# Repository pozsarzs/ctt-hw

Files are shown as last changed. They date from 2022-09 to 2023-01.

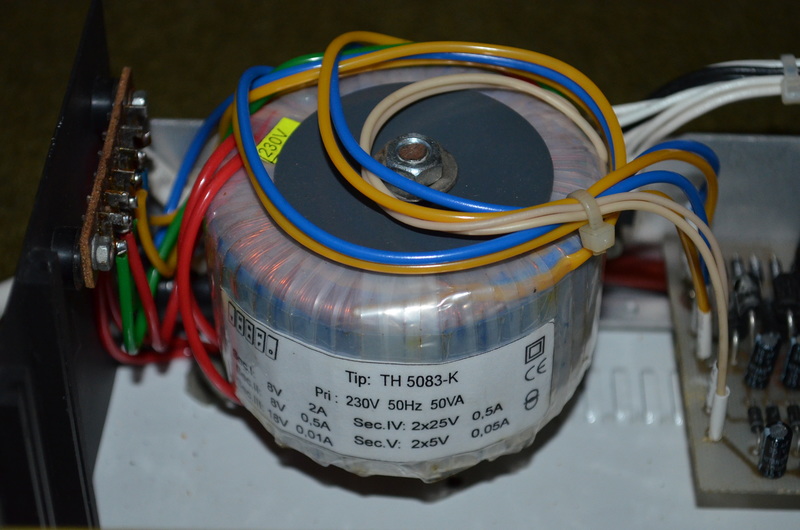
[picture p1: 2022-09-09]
photos/ctt-ps4.jpg

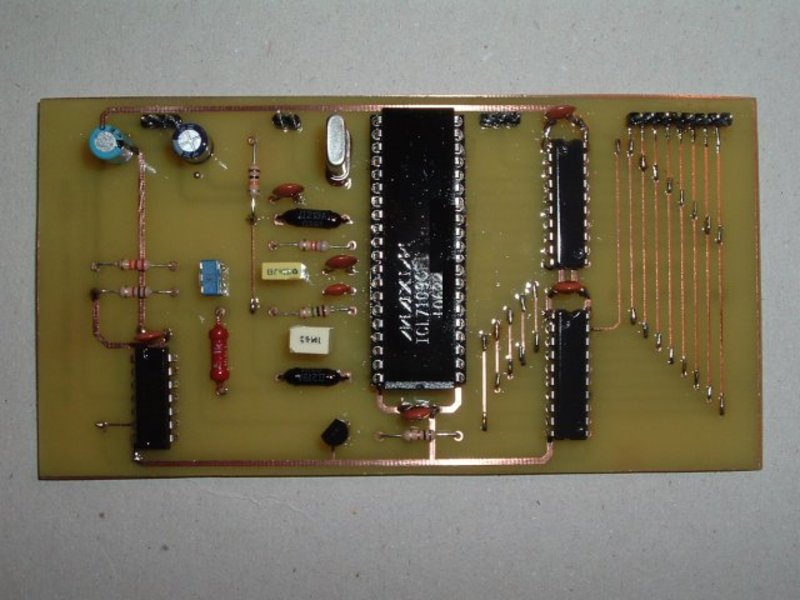
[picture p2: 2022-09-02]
photos/ctt-ad.jpg

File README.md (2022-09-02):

**CTT - transistor tester and characteristic curve plotter**  
Copyright (C) 2010-2022 Pozsár Zsolt <pozsarzs@gmail.com>  
Homepage: <http://www.pozsarzs.hu/>  
GitHub: <https://github.com/pozsarzs/ctt-hw>

**Documentation**

- version:             1.0
- language:            en
- licence:             CC-BY-NC-4.0

**Hardware**

 - version:            v120128

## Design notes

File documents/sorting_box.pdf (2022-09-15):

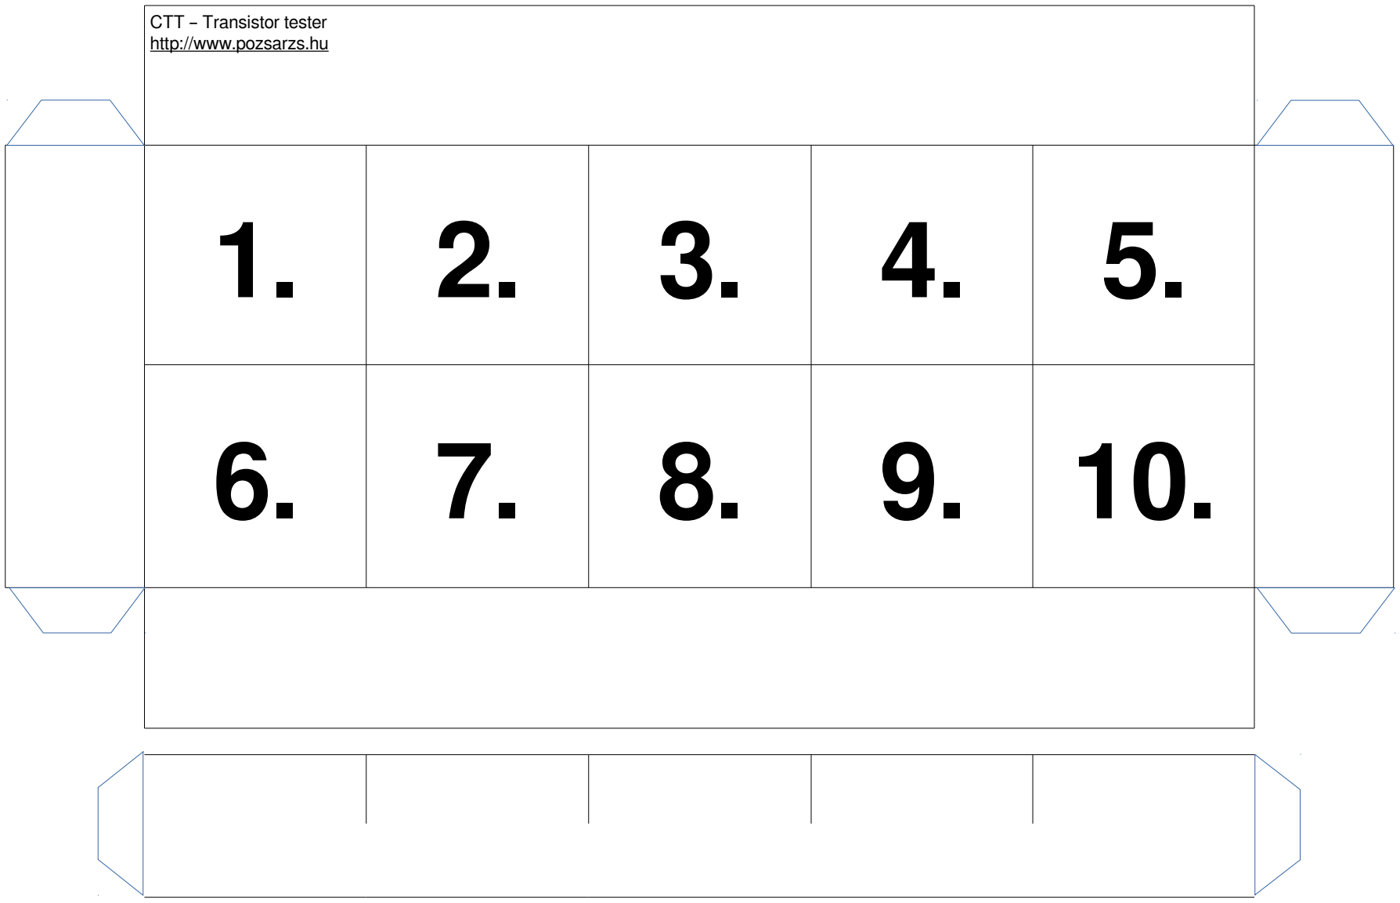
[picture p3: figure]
CTT – Transistor tester http://www.pozsarzs.hu

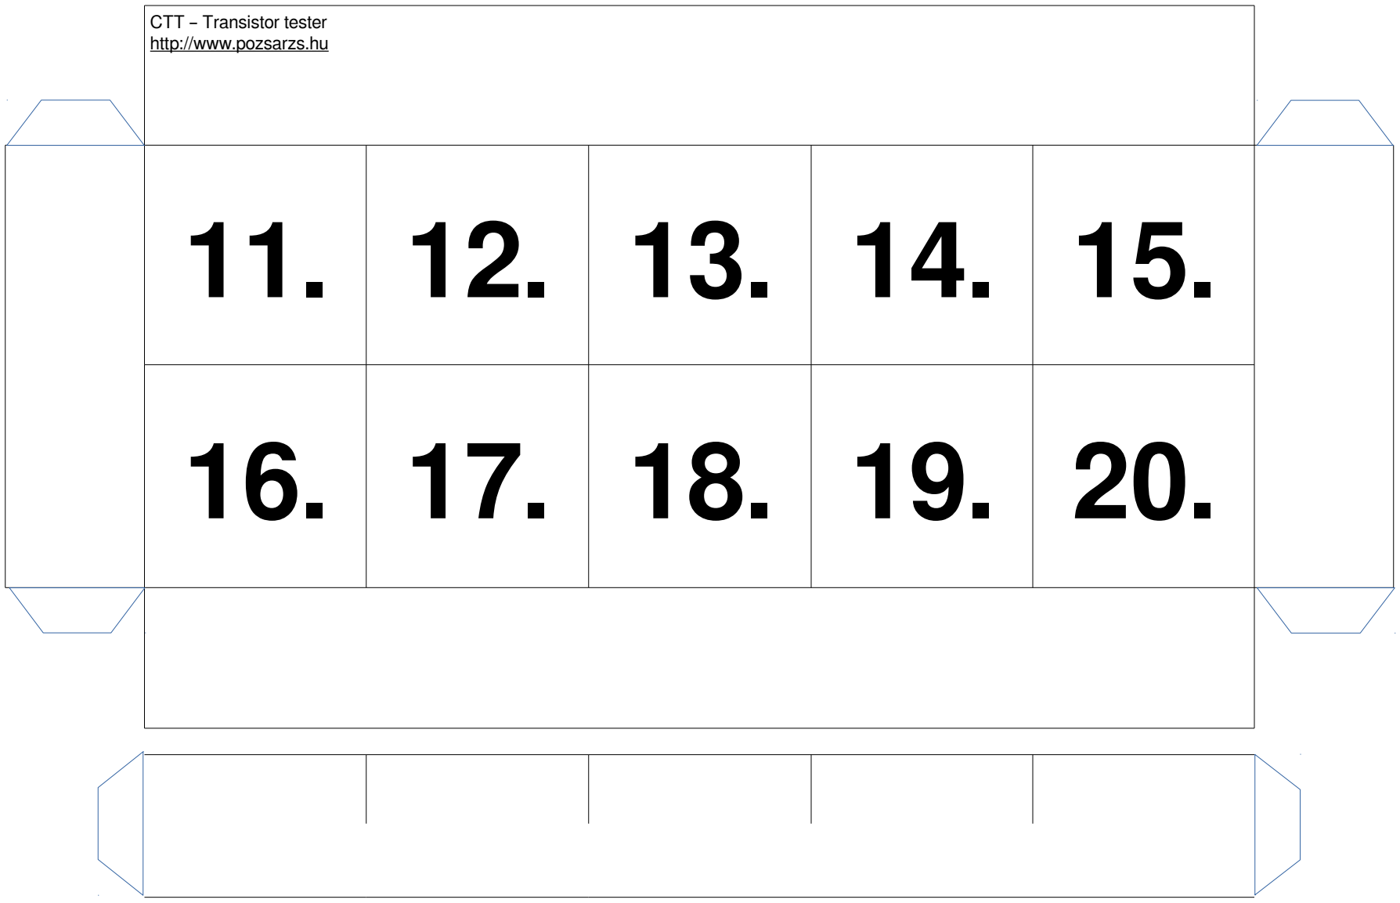
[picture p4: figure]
CTT – Transistor tester http://www.pozsarzs.hu

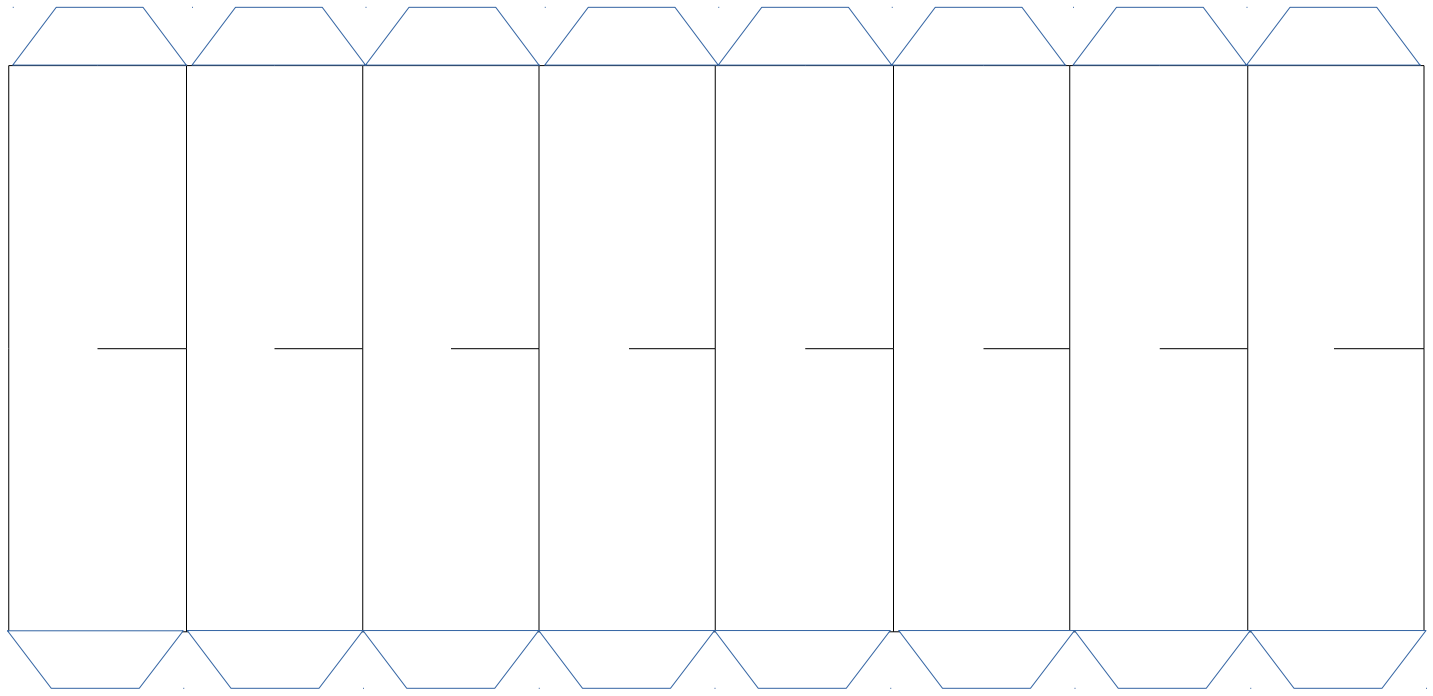
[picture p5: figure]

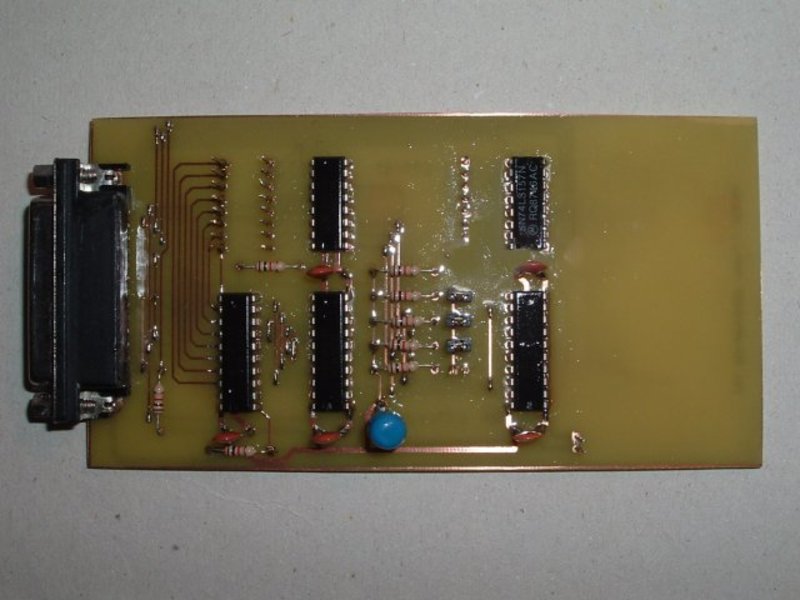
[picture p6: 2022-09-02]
photos/ctt-if.jpg

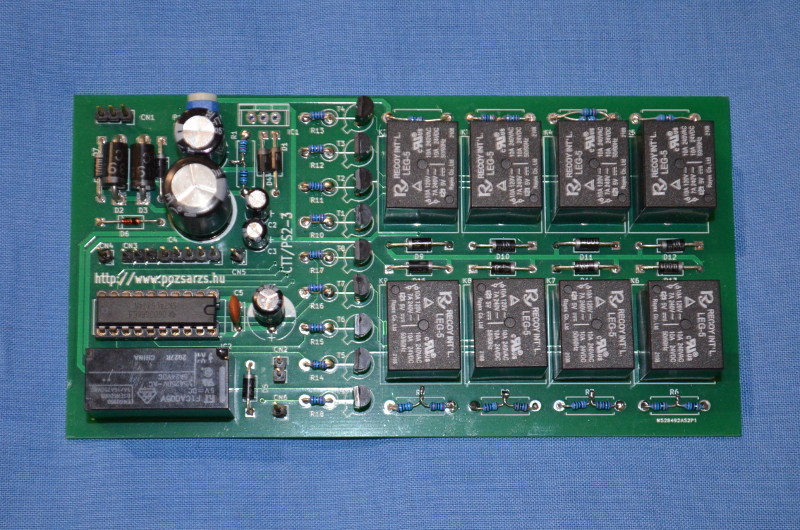
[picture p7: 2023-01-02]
photos/ctt-ps2.jpg

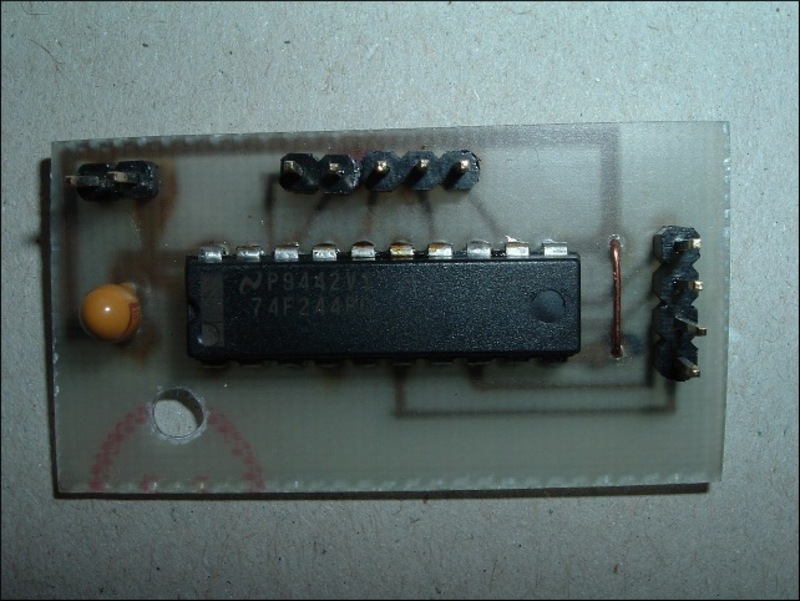
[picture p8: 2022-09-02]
photos/ctt-sc.jpg

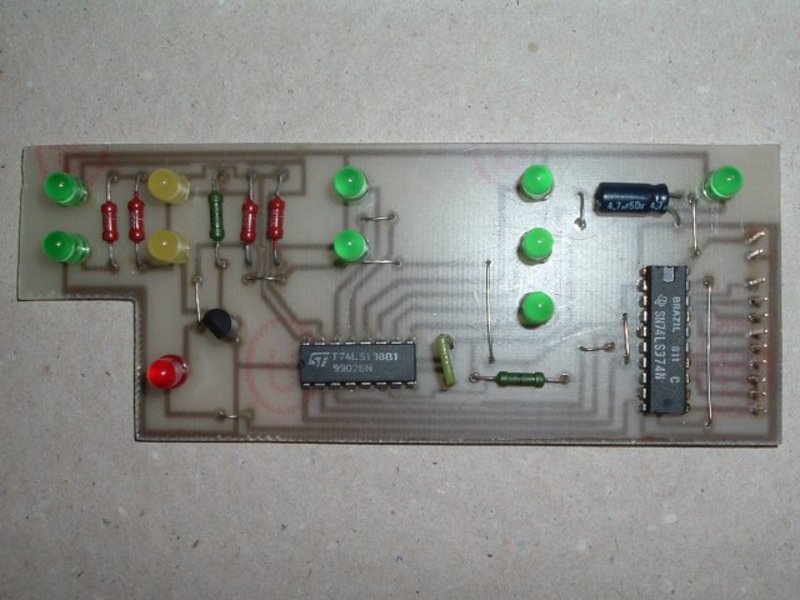
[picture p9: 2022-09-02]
photos/ctt-dp.jpg

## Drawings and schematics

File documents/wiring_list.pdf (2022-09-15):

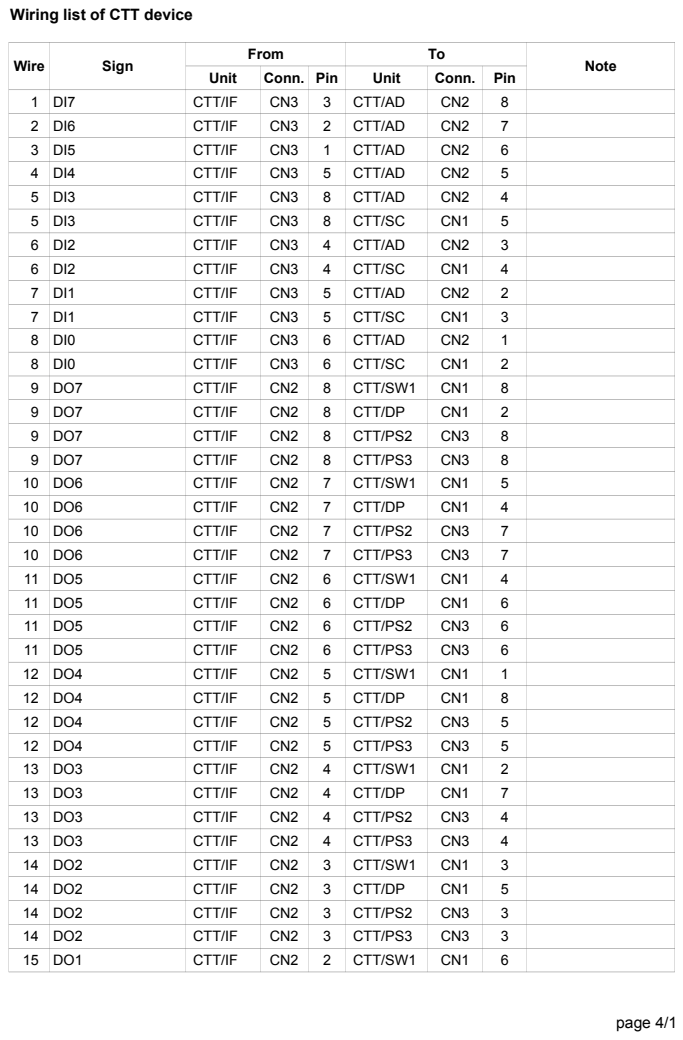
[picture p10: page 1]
Wire; Sign; From; Note; Unit; Conn. Pin; CTT/IF; CTT/AD; CTT/SC; CTT/SW1; CTT/DP; CTT/PS2; CTT/PS3

Wiring list of CTT device

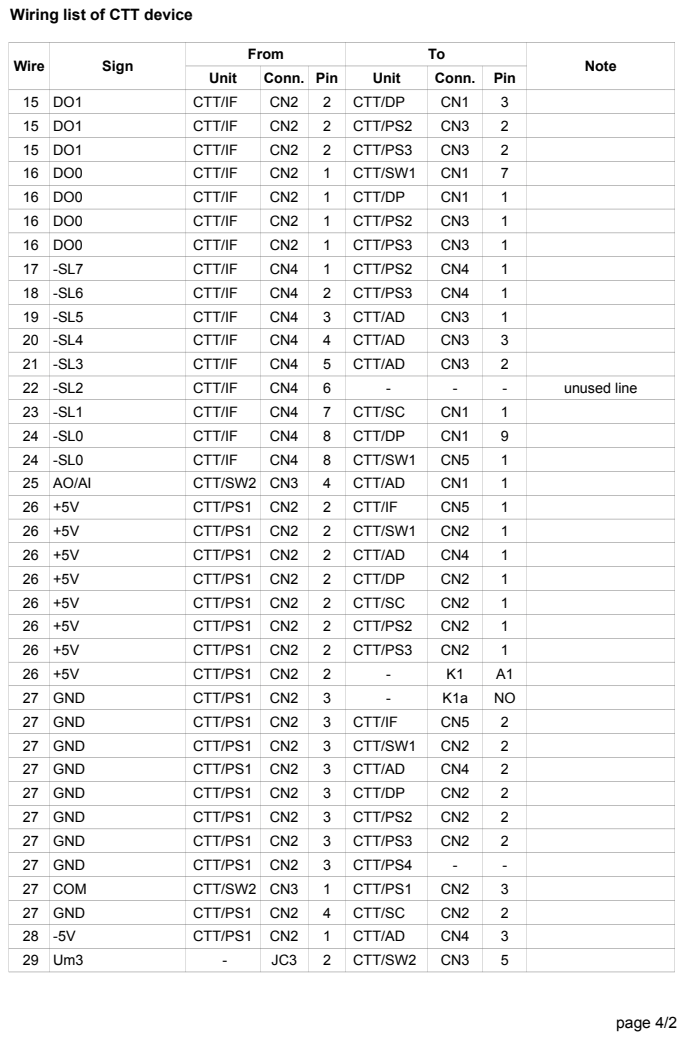
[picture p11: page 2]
Wire; Sign; Note; Unit; Conn. Pin; CTT/IF; CTT/DP; CTT/PS2; CTT/PS3; CTT/SW1; CTT/AD; unused line; CTT/SC; CTT/SW2 CN3; CTT/PS1 CN2; 27 GND; CTT/PS4; 27 COM; CTT/PS1; CTT/SW2

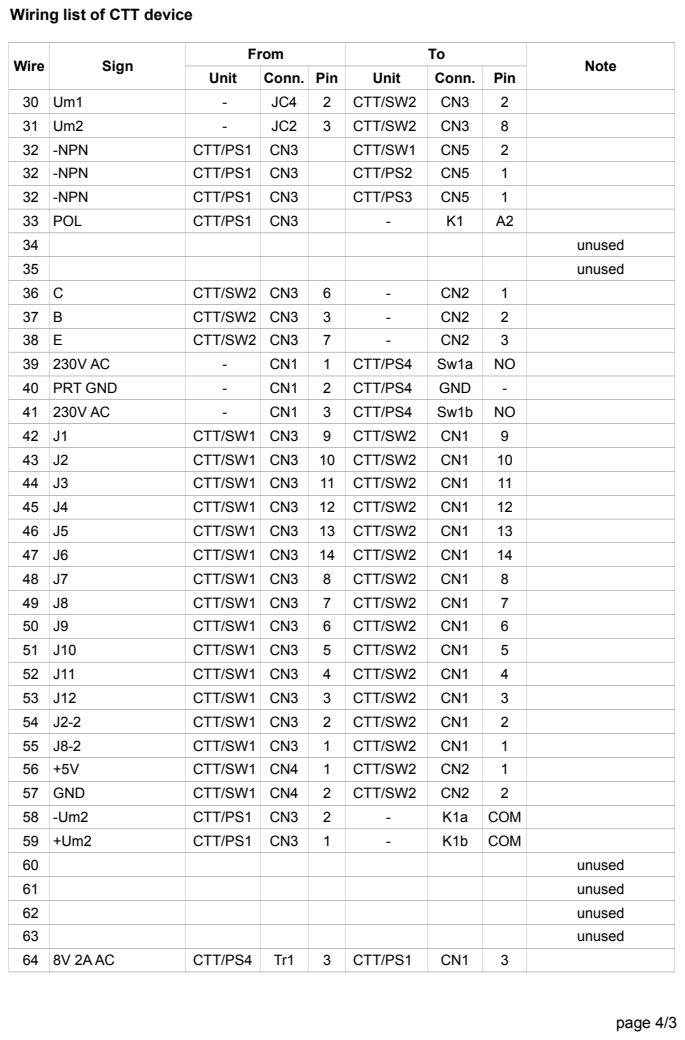
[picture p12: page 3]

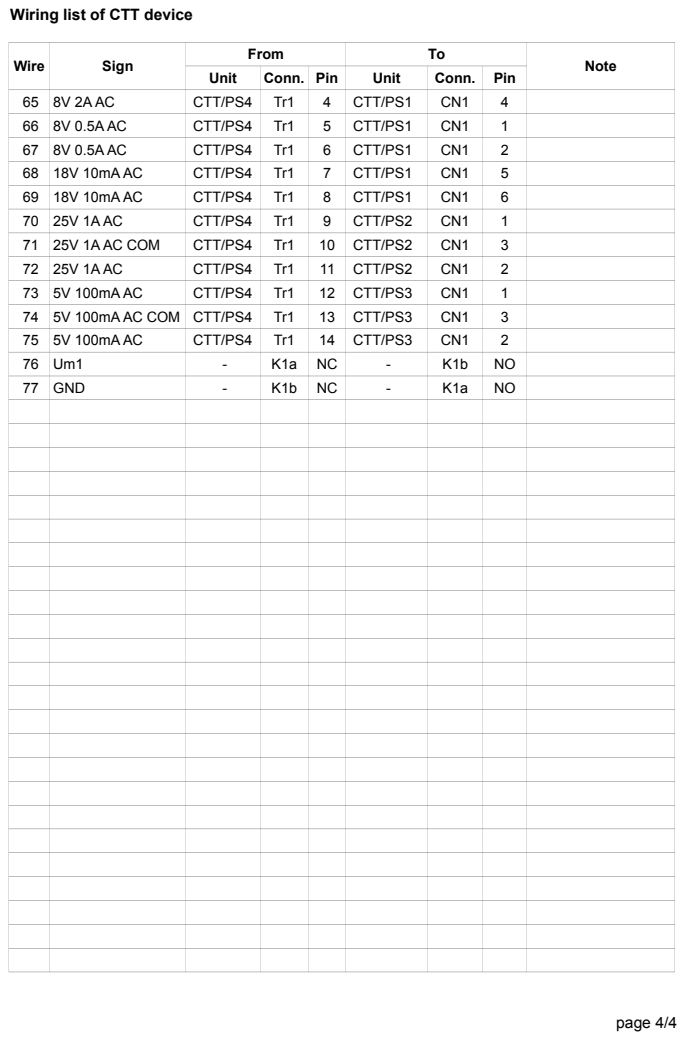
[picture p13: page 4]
Wire; Sign; Note; Unit; Conn. Pin; CTT/PS4; CTT/PS1; CTT/PS2; 71 25V 1A AC COM; 10 CTT/PS2; 11 CTT/PS2; 12 CTT/PS3; 74 5V 100mA AC COM CTT/PS4; 13 CTT/PS3; 14 CTT/PS3; 77 GND

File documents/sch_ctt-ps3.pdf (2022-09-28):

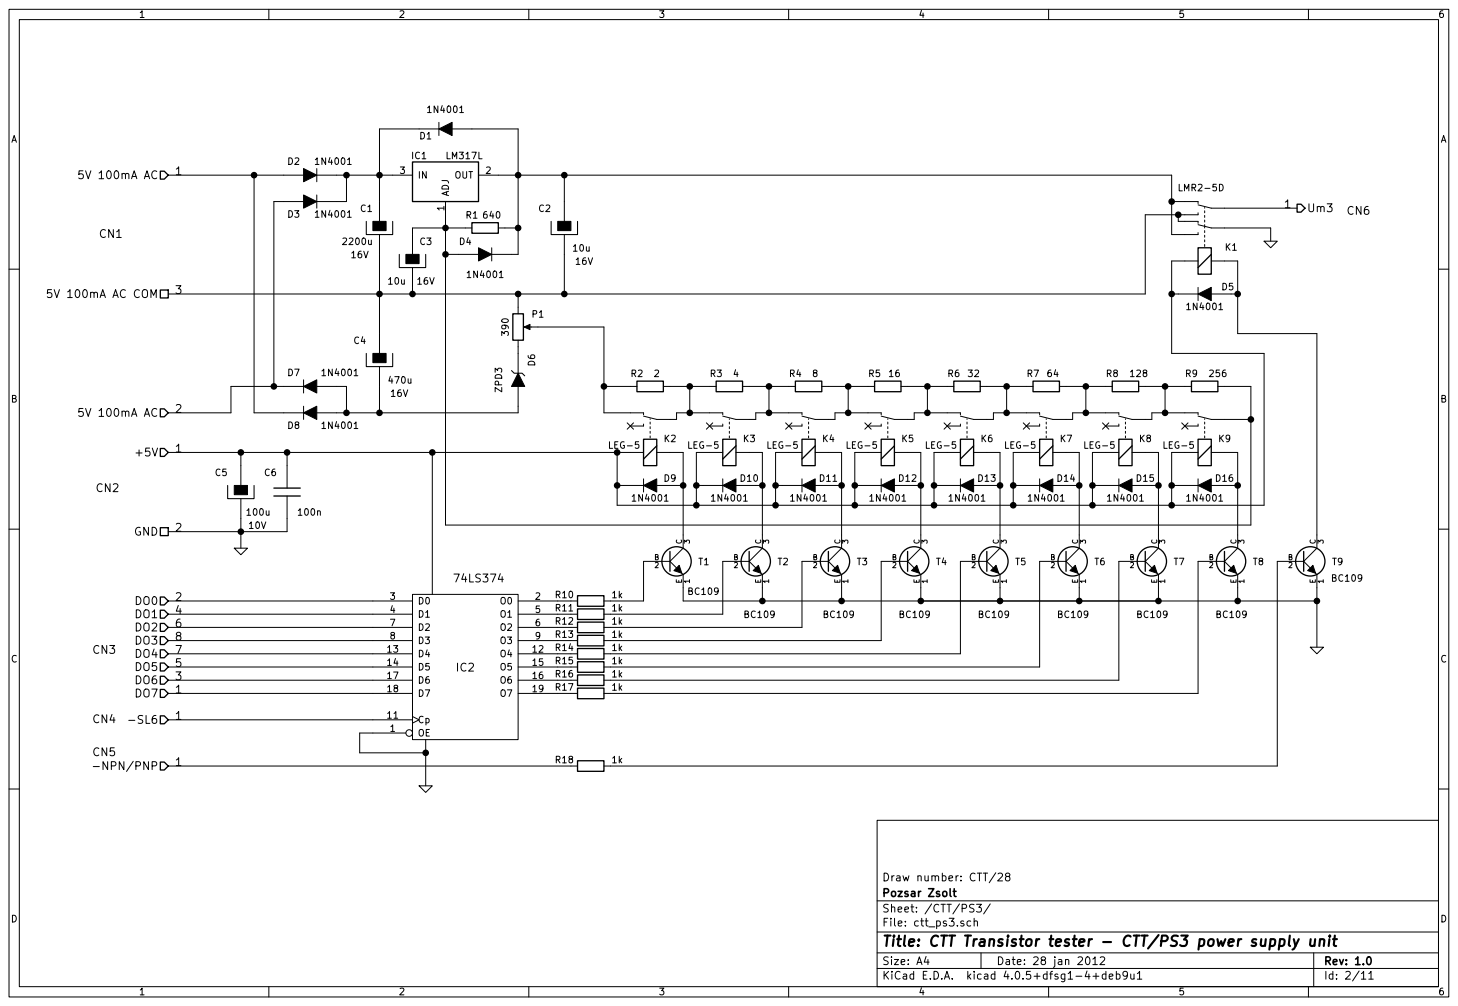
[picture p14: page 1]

File: ctt_ps3.sch Sheet: /CTT/PS3/ Pozsar Zsolt Draw number: CTT/28

Id: 2/11 Title: CTT Transistor tester - CTT/PS3 power supply unit

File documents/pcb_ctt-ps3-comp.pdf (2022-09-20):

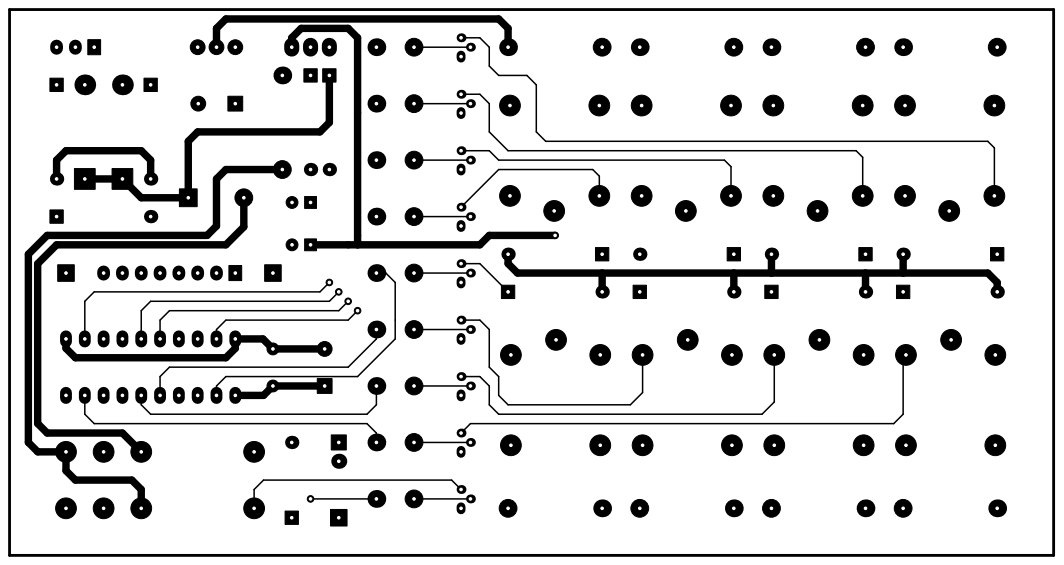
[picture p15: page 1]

File: ctt_ps3.kicad_pcb Sheet: Pozsar Zsolt Draw number: CTT/28, CTT/29-21

Id: 1/1 Title: CTT Transistor Tester - CTT/PS3 power supply unit

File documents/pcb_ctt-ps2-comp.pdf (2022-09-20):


File: ctt_ps2.kicad_pcb Sheet: Pozsar Zsolt Draw number: CTT/24, CTT/25-27

Id: 1/1 Title: CTT Transistor Tester - CTT/PS2 power supply unit

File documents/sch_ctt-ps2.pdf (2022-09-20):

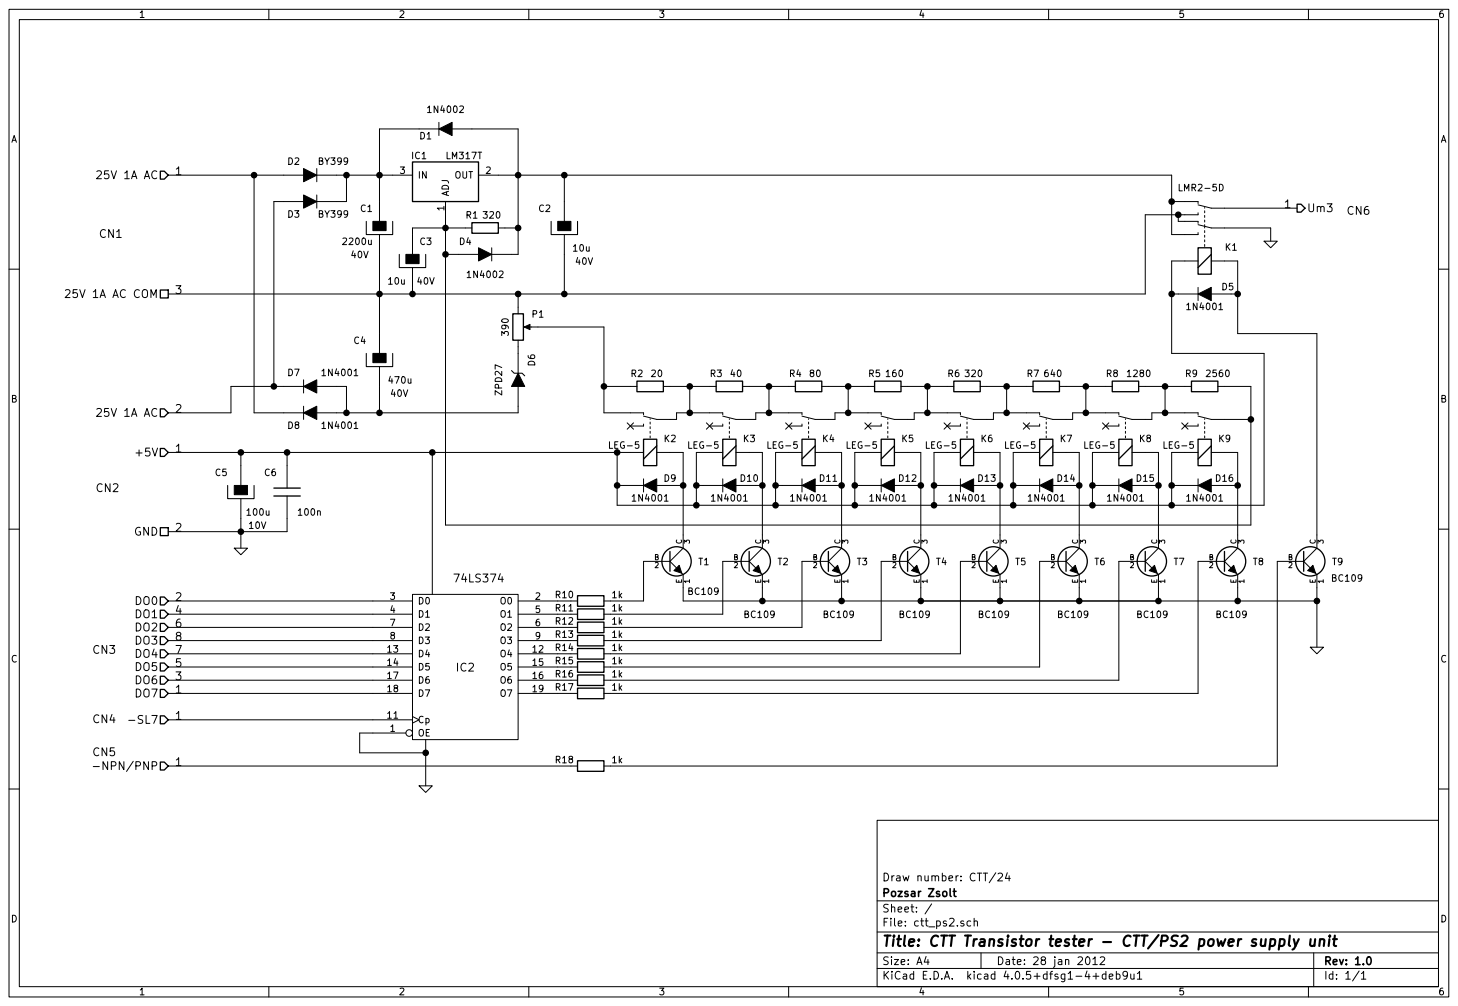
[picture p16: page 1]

File: ctt_ps2.sch Sheet: / Pozsar Zsolt Draw number: CTT/24

Id: 1/1 Title: CTT Transistor tester - CTT/PS2 power supply unit

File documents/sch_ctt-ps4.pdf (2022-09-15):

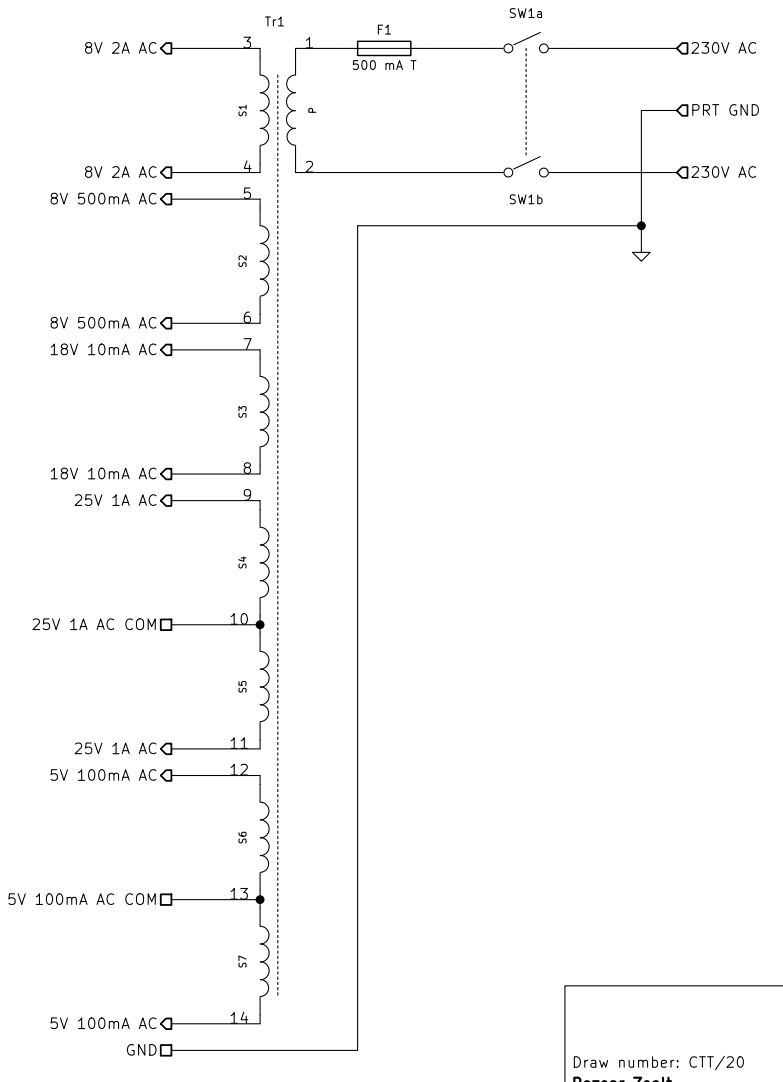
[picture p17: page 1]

File: ctt_ps4.sch Sheet: /CTT/PS4/ Pozsar Zsolt Draw number: CTT/20

Id: 10/11 Title: CTT Transistor tester - CTT/PS4 power supply unit

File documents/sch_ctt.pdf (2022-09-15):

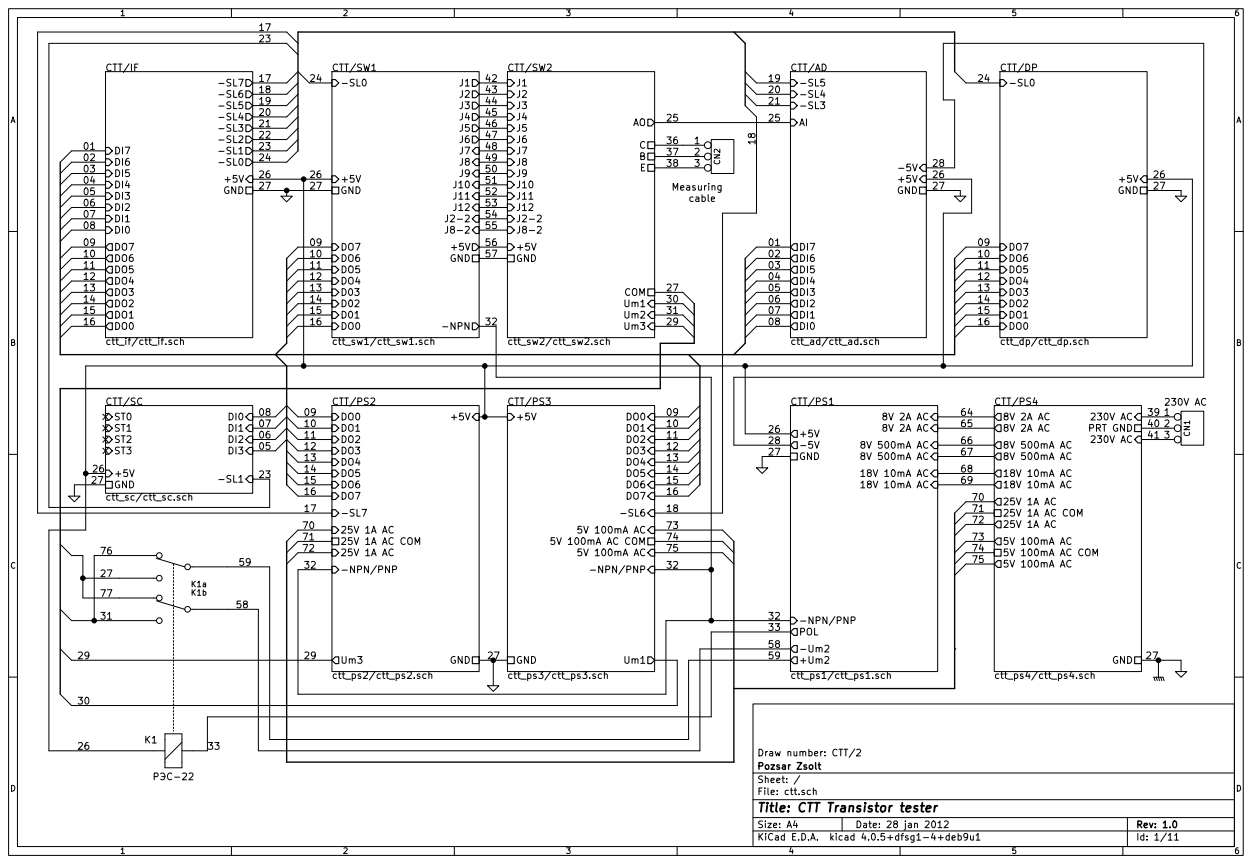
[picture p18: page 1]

33
58
59

Id: 1/11 Title: CTT Transistor tester File: ctt.sch Sheet: / Pozsar Zsolt Draw number: CTT/2 29
ctt_ps2/ctt_ps2.sch

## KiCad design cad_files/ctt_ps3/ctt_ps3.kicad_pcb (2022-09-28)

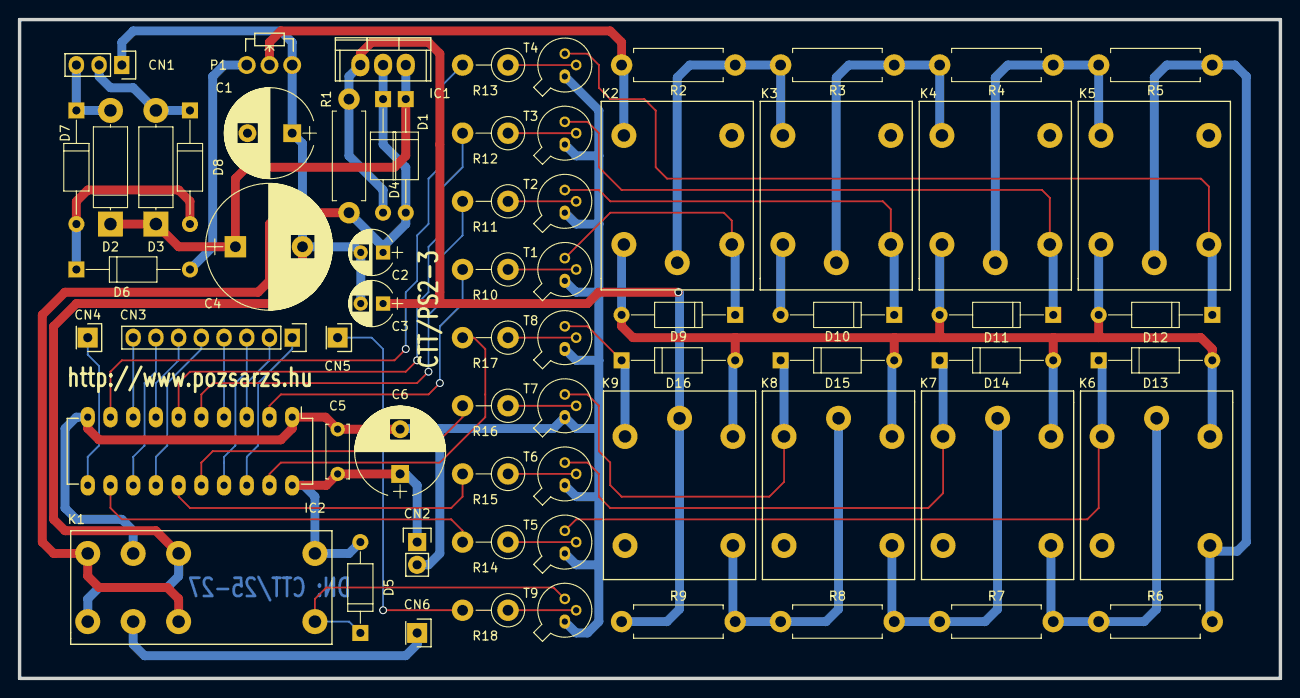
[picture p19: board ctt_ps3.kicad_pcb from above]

Board: 2 copper layers, 141.0 x 73.7 mm, 67 parts (0 on the bottom side), 43 nets.

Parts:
C1: 2200u; CP_Radial_D14.0mm_P7.50mm
C2, C3: 10u; CP_Radial_D5.0mm_P2.50mm
C4: 470u; CP_Radial_D10.0mm_P5.00mm
C5: 100u; CP_Radial_D10.0mm_P5.00mm
C6: 100n; C_Disc_D6.0mm_W2.5mm_P5.00mm
CN1: Pin_Header_Straight_1x03
CN2: Pin_Header_Straight_1x02
CN3: Pin_Header_Straight_1x08
CN4, CN5, CN6: Pin_Header_Straight_1x01
D1, D4: 1N4002; D_A-405_P12.70mm_Horizontal
D2, D3: BY399; D_5W_P12.70mm_Horizontal
D5: 1N4001; D_A-405_P10.16mm_Horizontal
D6: ZPD27; D_A-405_P12.70mm_Horizontal
D7, D8, D9, D10, D11, D12, D13, D14, D15, D16: 1N4001; D_A-405_P12.70mm_Horizontal
IC1: LM317L; TO-220
IC2: 74LS374; DIP-20_W7.62mm_LongPads
K1: LMR2-5D; relay_lmr2
K2, K3, K4, K5, K6, K7, K8, K9: LEG-5; relay_leg
P1: 390; Potentiometer_WirePads_Small
R1: 640; R_Axial_DIN0411_L9.9mm_D3.6mm_P12.70mm_Horizontal
R2: 2; R_Axial_DIN0411_L9.9mm_D3.6mm_P12.70mm_Horizontal
R3: 4; R_Axial_DIN0411_L9.9mm_D3.6mm_P12.70mm_Horizontal
R4: 8; R_Axial_DIN0411_L9.9mm_D3.6mm_P12.70mm_Horizontal
R5: 16; R_Axial_DIN0411_L9.9mm_D3.6mm_P12.70mm_Horizontal
R6: 32; R_Axial_DIN0411_L9.9mm_D3.6mm_P12.70mm_Horizontal
R7: 64; R_Axial_DIN0411_L9.9mm_D3.6mm_P12.70mm_Horizontal
R8: 128; R_Axial_DIN0411_L9.9mm_D3.6mm_P12.70mm_Horizontal
R9: 256; R_Axial_DIN0411_L9.9mm_D3.6mm_P12.70mm_Horizontal
R10, R11, R12, R13, R14, R15, R16, R17, R18: 1k; R_Axial_DIN0411_L9.9mm_D3.6mm_P5.08mm_Vertical
T1, T2, T3, T4, T5, T6, T7, T8, T9: BC109; TO-18-3

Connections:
/5V 100mA AC: D2.2, D3.2, D7.1, D8.1
/5V 100mA AC COM: C1.2, C2.2, C3.2, C4.1, K1.3, K1.6, P1.1
GND: C5.2, C6.2, IC2.1, IC2.10, K1.4, T1.1, T2.1, T3.1, T4.1, T5.1, T6.1, T7.1, T8.1, T9.1
unnamed: C1.1, D1.1, D2.1, D3.1, IC1.3
unnamed: C2.1, D1.2, D4.1, IC1.2, K1.5, K1.8, R1.1
unnamed: C3.1, D4.2, IC1.1, K9.3, R1.2, R9.1
unnamed: C4.2, D6.1, D7.2, D8.2
unnamed: D5.2, K1.2, T9.3
unnamed: D6.2, P1.3
unnamed: D9.2, K2.2, T1.3
unnamed: D10.2, K3.2, T2.3
unnamed: D11.2, K4.2, T3.3
unnamed: D12.2, K5.2, T4.3
unnamed: D13.2, K6.2, T5.3
unnamed: D14.2, K7.2, T6.3
unnamed: D15.2, K8.2, T7.3
unnamed: D16.2, K9.2, T8.3
unnamed: IC2.2, R10.2
unnamed: IC2.5, R11.2
unnamed: IC2.6, R12.2
unnamed: IC2.9, R13.2
unnamed: IC2.12, R14.2
unnamed: IC2.15, R15.2
unnamed: IC2.16, R16.2
unnamed: IC2.19, R17.2
unnamed: K2.3, K3.4, R2.1, R3.2
unnamed: K2.4, P1.2, R2.2
unnamed: K3.3, K4.4, R3.1, R4.2
unnamed: K4.3, K5.4, R4.1, R5.2
unnamed: K5.3, K6.4, R5.1, R6.2
unnamed: K6.3, K7.4, R6.1, R7.2
unnamed: K7.3, K8.4, R7.1, R8.2
unnamed: K8.3, K9.4, R8.1, R9.2
unnamed: R10.1, T1.2
unnamed: R11.1, T2.2
unnamed: R12.1, T3.2
unnamed: R13.1, T4.2
unnamed: R14.1, T5.2
unnamed: R15.1, T6.2
unnamed: R16.1, T7.2
unnamed: R17.1, T8.2
unnamed: R18.1, T9.2
VCC: C5.1, C6.1, D5.1, D9.1, D10.1, D11.1, D12.1, D13.1, D14.1, D15.1, D16.1, IC2.20, K1.1, K2.1, K3.1, K4.1, K5.1, K6.1, K7.1, K8.1, K9.1

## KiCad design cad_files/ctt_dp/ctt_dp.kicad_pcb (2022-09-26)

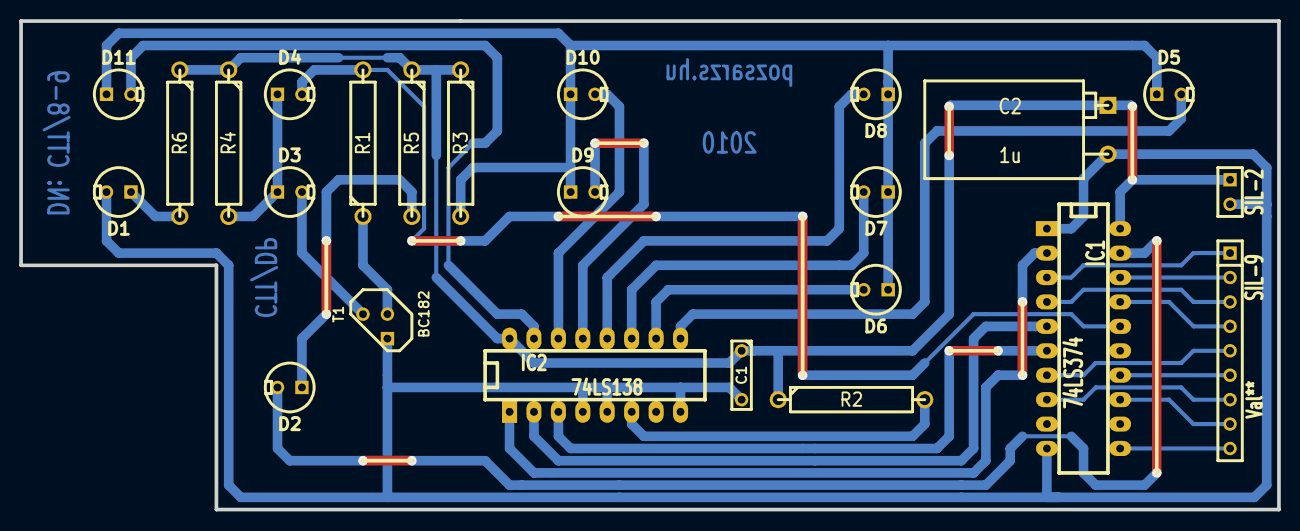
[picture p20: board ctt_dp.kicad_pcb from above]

Board: 2 copper layers, 130.8 x 50.8 mm, 24 parts (0 on the bottom side), 21 nets.

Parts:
C1: 33n; C2
C2: 1u; CPR10X16
D1, D2, D3, D4, D5, D6, D7, D8, D9, D10, D11: LED; LEDV
IC1: 74LS374; 20DIP-ELL300
IC2: 74LS138; 16DIP-ELL300
R1, R2: 1k; R6
R3, R4, R5, R6: 330; R6
SIL-2: Val**; SIL-2
SIL-9: Val**; SIL-9
T1: BC182; TO92

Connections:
+5V: C1.1, C2.1, IC1.20, IC2.16, R2.1, R3.1, R4.1, R5.1, R6.1
GND: C1.2, C2.2, D1.2, IC1.1, IC1.10, IC2.4, IC2.5, IC2.8, T1.1
unnamed: D1.1, R6.2
unnamed: IC2.6, R2.2
unnamed: R1.1, T1.2
unnamed: D4.2, IC1.16, R1.2
unnamed: D2.1, R5.2
unnamed: IC1.5, IC2.2
unnamed: D5.1, D6.1, D7.1, D8.1, D9.1, D10.1, D11.1, R3.2
unnamed: D6.2, IC2.10
unnamed: D8.2, IC2.12
unnamed: D10.2, IC2.14
unnamed: D11.2, IC2.15
unnamed: D9.2, IC2.13
unnamed: D7.2, IC2.11
unnamed: D5.2, IC2.9
unnamed: IC1.2, IC2.1
unnamed: IC1.6, IC2.3
unnamed: D3.1, D4.1, R4.2
unnamed: D3.2, T1.3
unnamed: D2.2, IC1.19

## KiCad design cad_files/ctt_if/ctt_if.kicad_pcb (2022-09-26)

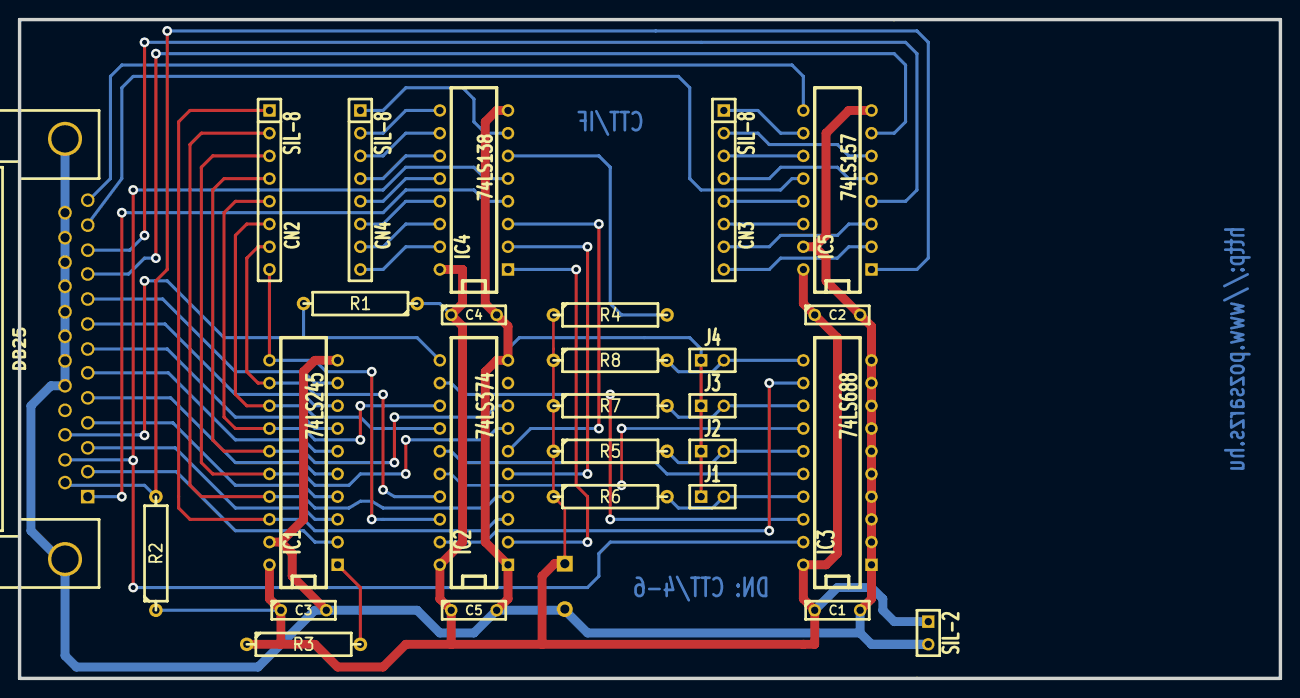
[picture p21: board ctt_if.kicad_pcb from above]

Board: 2 copper layers, 141.0 x 73.7 mm, 28 parts (1 on the bottom side), 39 nets.

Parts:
C1, C2, C3, C4, C5: 33n; C2
C6: 100u; CPR10X16
CN1: DB25; DB25FC
IC1: 74LS245; 20dip300
IC2: 74LS374; 20dip300
IC3: 74LS688; 20dip300
IC4: 74LS138; 16dip300
IC5: 74LS157; 16dip300
J1, J2, J3, J4: JUMPER; SIL-2
R1, R2, R3, R4, R5, R6, R7, R8: 1k; R5
SIL-2: CN5; SIL-2
SIL-8: CN3; SIL-8
SIL-8#2: CN4; SIL-8
SIL-8#3: CN2; SIL-8

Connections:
/+5V: C1.1, C2.1, C3.1, C4.1, C5.1, C6.1, IC1.20, IC2.20, IC3.20, IC4.16, IC5.16, R1.1, R2.1, R3.1, R4.1, R5.1, R6.1, R7.1, R8.1
/DO0: IC1.18, IC2.3
/DO1: IC1.17, IC2.4
/DO2: IC1.16, IC2.7
/DO3: IC1.15, IC2.8
/DO4: IC1.14, IC2.13
/DO5: IC1.13, IC2.14
/DO6: IC1.12, IC2.17
/DO7: IC1.11, IC2.18
/GND: C1.2, C2.2, C3.2, C4.2, C5.2, C6.2, CN1.18, CN1.19, CN1.20, CN1.21, CN1.22, CN1.23, CN1.24, CN1.25, IC1.10, IC1.19, IC2.1, IC2.10, IC3.1, IC3.2, IC3.3, IC3.4, IC3.5, IC3.6, IC3.7, IC3.8, IC3.9, IC3.10, IC4.8, IC5.8, IC5.15, J1.1, J2.1, J3.1, J4.1
unnamed: IC3.11, J4.2, R8.2
unnamed: IC3.13, J3.2, R7.2
unnamed: IC3.15, J2.2, R5.2
unnamed: IC2.15, IC3.16
unnamed: IC2.19, IC3.12
unnamed: IC3.17, J1.2, R6.2
unnamed: CN1.1, IC4.4
unnamed: IC2.5, IC4.2
unnamed: CN1.2, IC1.2
unnamed: IC2.16, IC3.14
unnamed: IC2.12, IC3.18
unnamed: CN1.16, IC2.11, R1.2
unnamed: CN1.13, IC5.9
unnamed: CN1.14, IC5.1, R2.2
unnamed: CN1.15, IC3.19, IC4.5
unnamed: CN1.12, IC5.12
unnamed: IC1.1, R3.2
unnamed: CN1.11, IC5.4
unnamed: IC4.6, R4.2
unnamed: CN1.4, IC1.4
unnamed: CN1.6, IC1.6
unnamed: CN1.8, IC1.8
unnamed: IC2.6, IC4.3
unnamed: IC2.2, IC4.1
unnamed: CN1.10, IC5.7
unnamed: CN1.9, IC1.9
unnamed: CN1.7, IC1.7
unnamed: CN1.5, IC1.5
unnamed: CN1.3, IC1.3

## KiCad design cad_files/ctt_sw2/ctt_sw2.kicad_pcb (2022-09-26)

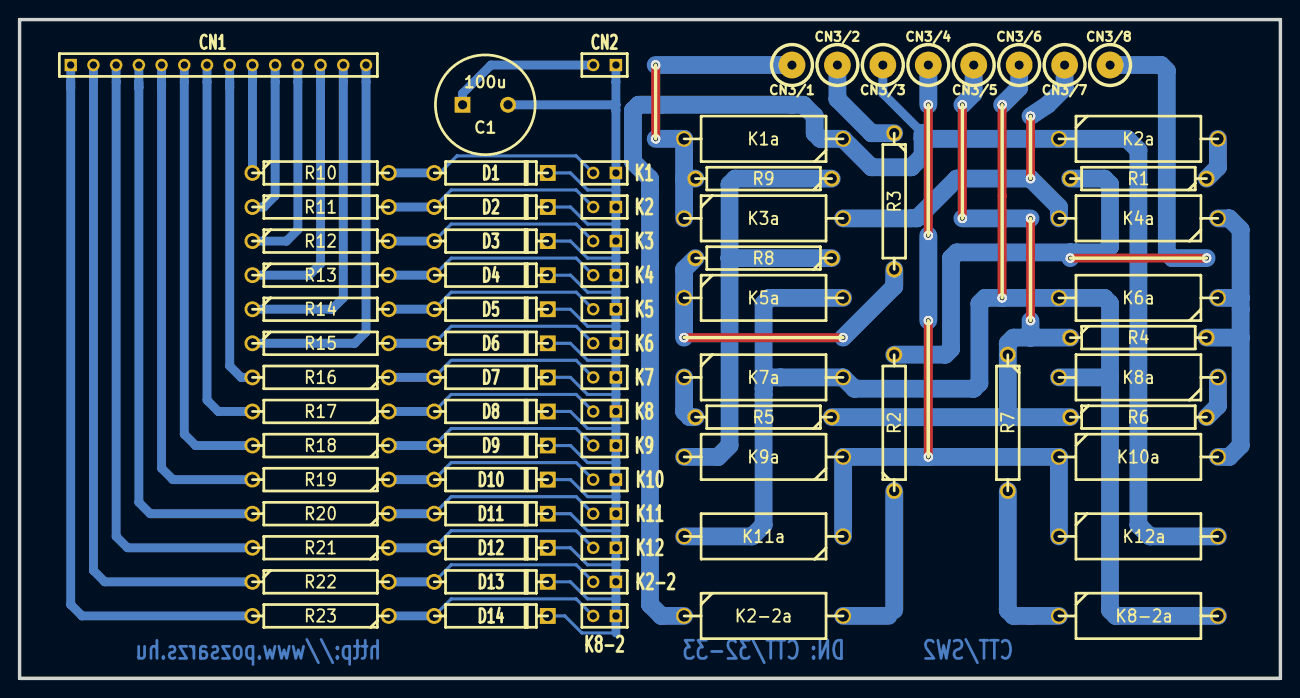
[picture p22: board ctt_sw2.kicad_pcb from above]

Board: 2 copper layers, 141.0 x 73.7 mm, 76 parts (0 on the bottom side), 30 nets.

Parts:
1PIN: CN3/8; 1pin3
1PIN#2: CN3/7; 1pin3
1PIN#3: CN3/6; 1pin3
1PIN#4: CN3/1; 1pin3
1PIN#5: CN3/2; 1pin3
1PIN#6: CN3/3; 1pin3
1PIN#7: CN3/4; 1pin3
1PIN#8: CN3/5; 1pin3
C1: 100u; C2V10
D1, D2, D3, D4, D5, D6, D7, D8, D9, D10, D11, D12, D13, D14: 1N4148; D5
K1, K2, K2-2, K3, K4, K5, K6, K7, K8, K8-2, K9, K10, K11, K12: Reed_relay; SIL-2
K1a, K2-2a, K2a, K3a, K4a, K5a, K6a, K7a, K8-2a, K8a, K9a, K10a, K11a, K12a: SPST; R7
R1, R5: 100_1%; R6
R2, R10, R11, R12, R13, R14, R15, R16, R17, R18, R19, R20, R21, R22, R23: R; R6
R3: 33K; R6
R4: 1k_1%; R6
R6: 1_1%_1W; R6
R7: ?_1%_1W; R6
R8: 900K_1%; R6
R9: 100k_1%; R6
SIL-2: CN2; SIL-2
SIL-14: CN1; SIL-14

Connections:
0-1V_1: R1.2, R2.2
0-20V_1: R4.1, R5.1, R6.1, R7.1
+5V_1: C1.1, D1.2, D2.2, D3.2, D4.2, D5.2, D6.2, D7.2, D8.2, D9.2, D10.2, D11.2, D12.2, D13.2, D14.2, K1.1, K2.1, K2-2.1, K3.1, K4.1, K5.1, K6.1, K7.1, K8.1, K8-2.1, K9.1, K10.1, K11.1, K12.1
Base_1: K1a.1, K2-2a.1, K2a.1, K12a.2
COM_1: K1a.2, K3a.1, R9.2
Collector_1: K5a.2, K6a.2, K7a.2, K8-2a.2, K8a.2, K11a.2
Emitter_1: K3a.2, K4a.2
unnamed: D12.1, K12.2, R21.1
unnamed: D11.1, K11.2, R20.1
unnamed: D10.1, K10.2, R19.1
unnamed: D9.1, K9.2, R18.1
unnamed: D7.1, K7.2, R16.1
unnamed: D3.1, K3.2, R12.2
unnamed: D4.1, K4.2, R13.2
unnamed: D5.1, K5.2, R14.2
unnamed: D2.1, K2.2, R11.2
unnamed: K2-2a.2, R2.1
unnamed: K4a.1, K6a.1, K10a.2, R4.2
unnamed: K7a.1, R5.2
unnamed: K8-2a.1, R7.2
unnamed: K8a.1, R6.2
unnamed: K5a.1, R3.2, R8.2
unnamed: K2a.2, R1.1
unnamed: K9a.2, R8.1, R9.1
unnamed: D1.1, K1.2, R10.2
unnamed: D13.1, K2-2.2, R22.2
unnamed: D6.1, K6.2, R15.2
unnamed: D14.1, K8-2.2, R23.1
unnamed: D8.1, K8.2, R17.1
Um_1: K9a.1, K10a.1, K11a.1, K12a.1

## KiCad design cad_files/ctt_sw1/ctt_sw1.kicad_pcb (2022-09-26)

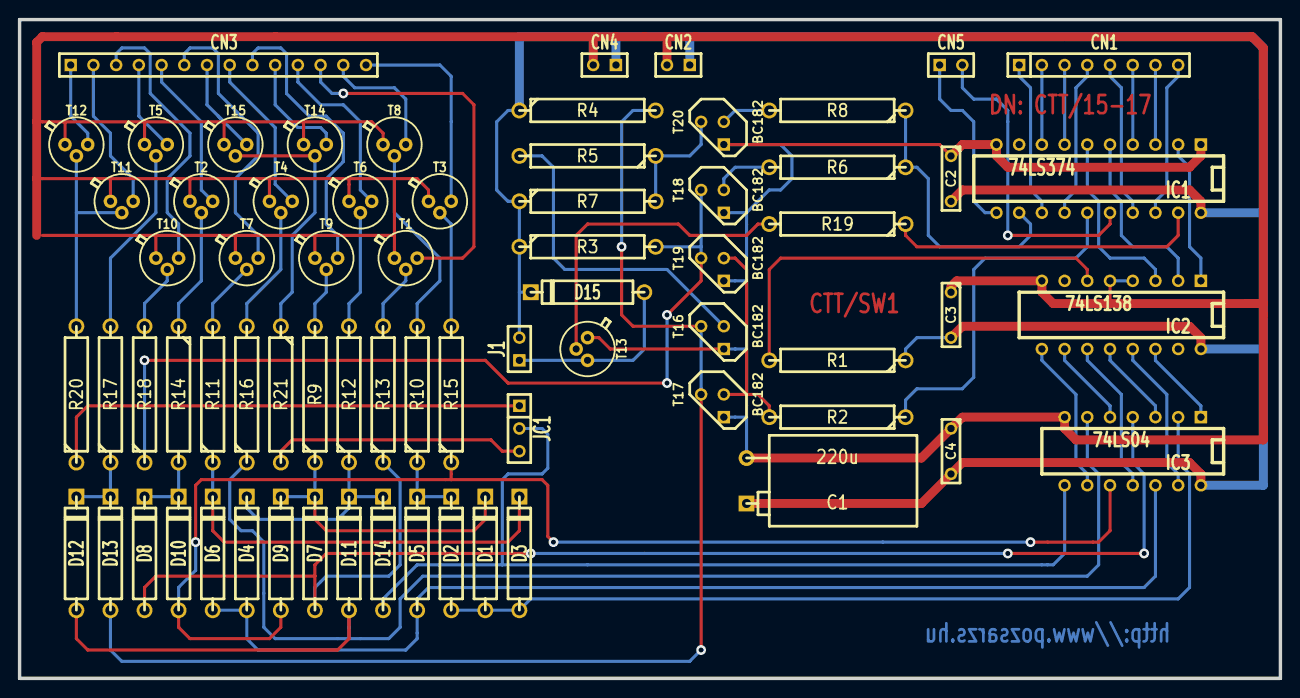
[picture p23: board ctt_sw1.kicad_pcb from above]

Board: 2 copper layers, 141.0 x 73.7 mm, 70 parts (0 on the bottom side), 50 nets.

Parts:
C1: 220u; CPR10X16
C2, C3, C4: 100n; C2
D1, D2, D3, D4, D5, D6, D7, D8, D9, D10, D11, D12, D13, D14, D15: 1N4148; D5
IC1: 74LS374; DIP-20__300
IC2: 74LS138; DIP-16__300
IC3: 74LS04; DIP-14__300
J1: Reed_relay; SIL-2
JC1: SWITCH_INV; SIL-3
R1, R2, R3, R4, R5, R6, R7, R8, R9, R10, R11, R12, R13, R14, R15, R16, R17, R18, R19, R20, R21: 1k; R6
SIL-2: CN4; SIL-2
SIL-2#2: CN5; SIL-2
SIL-2#3: CN2; SIL-2
SIL-8: CN1; SIL-8
SIL-14: CN3; SIL-14
T1, T2, T3, T4, T5, T6, T7, T8, T9, T10, T11, T12, T13, T14, T15: BC109C; TO18EBC
T16, T17, T18, T19, T20: BC182; TO92

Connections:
/+5V: C1.1, C2.2, C3.2, C4.2, D15.2, IC1.20, IC2.16, IC3.14, J1.2, R1.1, R3.1, R4.1, R7.1
GND: C1.2, C2.1, C3.1, C4.1, IC1.1, IC1.10, IC2.4, IC2.5, IC2.8, IC3.7, T1.1, T2.1, T3.1, T4.1, T5.1, T6.1, T7.1, T8.1, T9.1, T10.1, T11.1, T12.1, T13.1, T14.1, T15.1, T16.1, T17.1, T18.1, T19.1, T20.1
unnamed: D13.1, R4.2, T16.3, T17.3
unnamed: R3.2, R18.1, T18.3, T19.3
unnamed: R2.2, T17.2, T19.2
unnamed: D1.2, D7.2, D9.2, R9.1
unnamed: D4.2, D11.2, D14.2, R12.1
unnamed: R20.2, T11.2, T12.2
unnamed: D1.1, D2.1, D3.1, IC3.2
unnamed: D4.1, D5.1, D6.1, IC3.12
unnamed: D3.2, D6.2, R11.1
unnamed: IC1.19, R19.1
unnamed: R19.2, T13.2
unnamed: JC1.3, R21.2
unnamed: JC1.1, R20.1
unnamed: R15.2, T3.2
unnamed: R14.1, T2.2
unnamed: IC1.15, R2.1
unnamed: R8.2, T20.2
unnamed: IC1.12, R6.1, R8.1
unnamed: R6.2, T18.2
unnamed: R5.2, T16.2
unnamed: R13.2, T1.2
unnamed: R12.2, T6.2
unnamed: R10.2, T8.2
unnamed: R9.2, T9.2
unnamed: IC2.9, IC3.9
unnamed: IC2.11, IC3.11
unnamed: IC2.12, IC3.3
unnamed: IC2.13, IC3.13
unnamed: IC2.6, R1.2
unnamed: IC2.10, IC3.5
unnamed: D14.1, IC3.8, JC1.2
unnamed: IC2.14, IC3.1
unnamed: R17.2, T5.2
unnamed: R21.1, T14.2, T15.2
unnamed: R11.2, T7.2
unnamed: R16.2, T4.2
unnamed: IC1.2, IC2.1
unnamed: IC1.5, IC2.2
unnamed: IC1.6, IC2.3
unnamed: R18.2, T10.2
unnamed: D15.1, J1.1, T13.3
unnamed: R5.1, R7.2, T20.3
unnamed: D2.2, D5.2, R10.1
unnamed: D8.2, D10.2, R14.2
unnamed: D12.2, D13.2, R17.1
unnamed: D7.1, D8.1, IC3.4, R13.1
unnamed: D9.1, D10.1, IC3.10, R15.1
unnamed: D11.1, D12.1, IC3.6, R16.1

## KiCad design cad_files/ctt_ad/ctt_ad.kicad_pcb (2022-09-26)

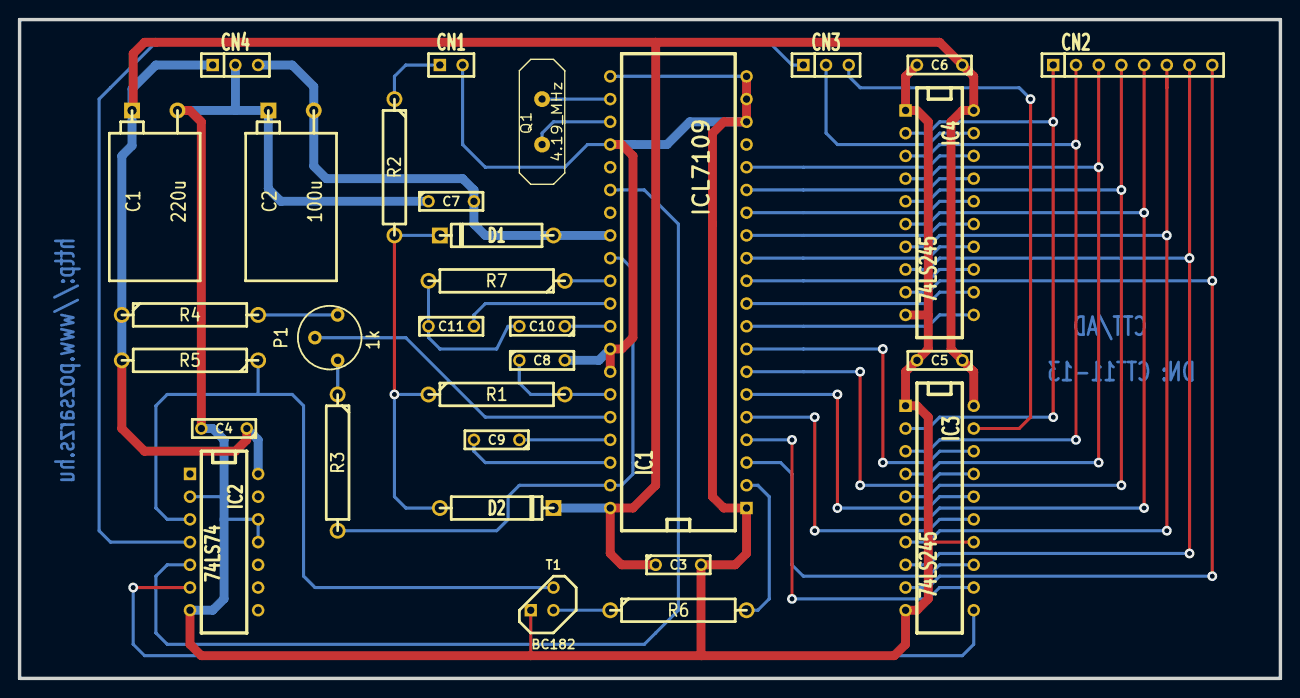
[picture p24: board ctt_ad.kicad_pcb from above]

Board: 2 copper layers, 141.0 x 73.7 mm, 31 parts (0 on the bottom side), 44 nets.

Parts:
C1: 220u; CPR10X16
C2: 100u; CPR10X16
C3, C4, C5, C6, C7, C10: 100n; C2
C8: 10n; C2
C9: 1u; C2
C11: 150n; C2
CN1: Val**; SIL-2
CN2: Val**; SIL-8
CN3, CN4: Val**; SIL-3
D1, D2: 1N4148; D5
IC1: ICL7109; 40dip600
IC2: 74LS74; 14dip300
IC3, IC4: 74LS245; 20dip300
P1: 1k; RV2
Q1: 4.19_MHz; HC-18UV
R1: 1M; R6
R2: 10k; R6
R3: 22k; R6
R4: 3.9k; R6
R5, R6: 1k; R6
R7: 82k; R6
T1: BC182; TO92

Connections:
+5V: C1.1, C3.1, C4.1, C5.1, C6.1, D2.2, IC1.40, IC2.14, IC3.20, IC4.20, R4.1, R5.2
-5VA: C2.2, C7.2, D1.1, IC1.28
DI0_1: IC3.2, IC4.2
DI1_1: IC3.3, IC4.3
DI2_1: IC3.4, IC4.4
DI3_1: IC3.5, IC4.5
DI4_1: IC3.6, IC4.6
DI5_1: IC3.7, IC4.7
DI6_1: IC3.8, IC4.8
DI7_1: IC3.9, IC4.9
GND: C1.2, C2.1, C3.2, C4.2, C5.2, C6.2, C7.1, C8.2, IC1.1, IC1.18, IC1.19, IC1.20, IC1.24, IC1.33, IC1.34, IC2.2, IC2.7, IC3.10, IC3.14, IC4.10, T1.1
unnamed: R6.1, T1.2
unnamed: IC2.3, R5.1, T1.3
unnamed: IC1.3, IC3.13
unnamed: IC1.2, R6.2
unnamed: C9.2, IC1.38
unnamed: IC1.23, Q1.1
unnamed: P1.3, R4.2
unnamed: D1.2, D2.1, R1.1, R2.2
unnamed: IC1.29, IC1.39, R3.2
unnamed: C11.2, IC1.31
unnamed: IC1.30, R7.1
unnamed: IC1.10, IC4.12
unnamed: IC1.12, IC4.14
unnamed: IC1.14, IC4.16
unnamed: IC1.16, IC4.18
unnamed: IC1.8, IC3.18
unnamed: IC1.6, IC3.16
unnamed: IC1.7, IC3.17
unnamed: IC1.5, IC3.15
unnamed: IC1.9, IC4.11
unnamed: IC1.15, IC4.17
unnamed: IC1.13, IC4.15
unnamed: IC1.11, IC4.13
unnamed: IC3.1, IC4.1
unnamed: C10.1, IC1.32
unnamed: C10.2, C11.1, R7.2
unnamed: IC1.35, R1.2
unnamed: P1.1, R3.1
unnamed: IC1.36, P1.2
unnamed: C9.1, IC1.37
unnamed: IC1.26, IC2.5
unnamed: IC1.4, IC3.12
unnamed: IC2.6, IC3.11

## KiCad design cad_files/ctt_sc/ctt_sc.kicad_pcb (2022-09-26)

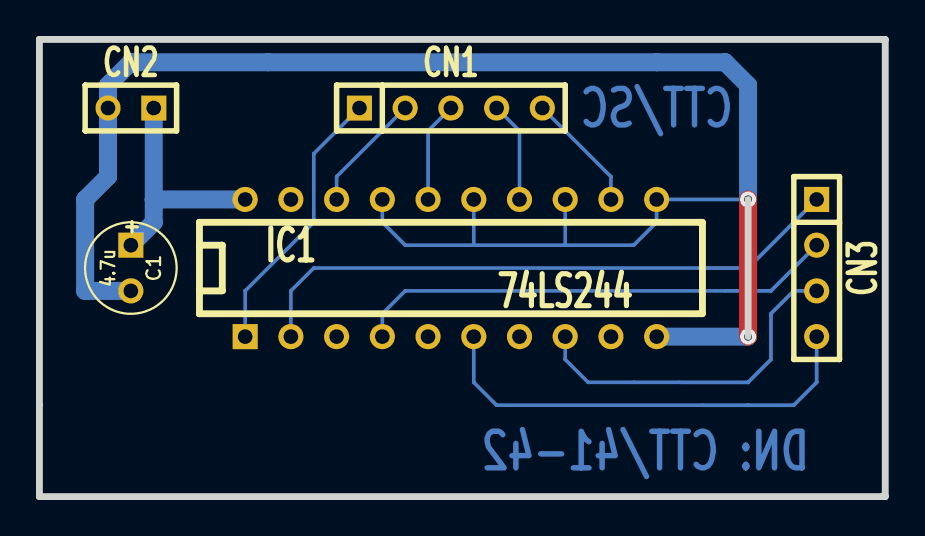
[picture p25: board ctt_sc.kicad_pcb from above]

Board: 2 copper layers, 47.0 x 25.4 mm, 5 parts (0 on the bottom side), 2 nets.

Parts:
C1: 4.7u; C1V5
IC1: 74LS244; DIP-20__300
SIL-2: CN2; SIL-2
SIL-4: CN3; SIL-4
SIL-5: CN1; SIL-5

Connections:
/GND: C1.2, IC1.10, IC1.11, IC1.13, IC1.15, IC1.17
VCC: C1.1, IC1.20

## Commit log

2011-03-27 Mar kesz fajlok beimportalasa
    [ctt.sch, ctt_ad.brd, ctt_ad.sch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]
2011-03-27 2011. 03. 27. délutáni állapot
    [ctt.sch, ctt_sw1.sch, ctt_sw2.sch]
2011-04-02 2011. 04. 02. reggeli állapot
    [ctt_sw1.brd, ctt_sw1.sch, ctt_sw2.sch]
2011-04-02 2011. 04. 02. délelőtti állapot
    [ctt_sw1.brd]
2011-04-14 2011.04.14-i állapot.
    [ctt.sch, ctt_ad.sch, ctt_dp.sch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]
2011-04-18 2011.04.18-i állapot.
    [ctt.sch, ctt_ad.sch, ctt_dp.sch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]
2011-04-18 2011.04.18.esti állapot.
    [ctt.sch, ctt_ad.sch, ctt_dp.sch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]
2011-04-20 2011.04.20-i állapot.
    [ctt.sch, ctt_ad.sch, ctt_dp.sch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]
2011-05-01 2011. 05. 01-i állapot.
    [ctt.sch, ctt_ad.sch, ctt_dp.sch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]
2011-05-07 2011. 05. 07-i állapot.
    [ctt_sw2.sch]
2011-05-08 2011. 05. 08-i állapot.
    [ctt_sw2.brd]
2011-05-10 2011. 05. 10-i állapot.
    [ctt_sw2.sch]
2011-05-14 2011. 05. 14. 16.16 állapot.
    [ctt_sw1.brd, ctt_sw1.sch]
2011-05-15 2011. 05. 15. du.-i állapot.
    [ctt_ps2.sch, ctt_ps3.sch]
2011-05-15 2011. 05. 15. esti állapot.
    [ctt.sch, ctt_ps.sch, ctt_ps1.sch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]
2011-05-17 2011.04.16-i állapot.
    [ctt.sch, ctt_ad.sch, ctt_dp.sch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]
2011-05-17 2011.04.16. esti állapot.
    [ctt.sch, ctt_ad.sch, ctt_dp.sch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]
2011-05-19 2011.05.19-i állapot.
    [ctt.sch, ctt_ad.sch, ctt_dp.sch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]
2011-05-22 2011.05.22-i állapot.
    [ctt.sch, ctt_ad.sch, ctt_dp.sch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]
2011-05-22 2011.05.22.esti állapot.
    [ctt.sch, ctt_ad.sch, ctt_dp.sch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]
2011-05-26 2011.05.26.esti állapot.
    [ctt.sch, ctt_ad.sch, ctt_dp.sch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]
2011-05-28 2011.05.28-i állapot.
    [ctt.sch, ctt_ad.sch, ctt_dp.sch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]
2011-06-04 2011.06.04-i állapot.
    [ctt.sch, ctt_ad.sch, ctt_dp.sch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]
2011-06-04 2011.06.04-i állapot. #2
    [ctt.sch, ctt_ad.sch, ctt_dp.sch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]
2011-06-05 2011.06.05-i állapot.
    [ctt.sch, ctt_ad.sch, ctt_dp.sch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]
2011-06-05 2011.06.05-i állapot. #2
    [ctt.sch, ctt_ad.sch, ctt_dp.sch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]
2011-06-05 2011.06.05. esti állapot.
    [ctt_sc.brd, ctt_wire.xls]
2011-06-07 2011.06.07-i állapot.
    [ctt.sch, ctt_ad.sch, ctt_dp.sch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]
2011-06-07 2011.06.07. esti állapot.
    [ctt_ps2.brd, ctt_ps2.sch]
2011-06-07 2011.06.07. esti állapot. #2
    [ctt_ps2.brd]
2011-06-11 2011.06.11-i állapot.
    [film2.brd]
2011-07-29 07.28-i állapot.
    [ctt.sch, ctt_ad.sch, ctt_dp.sch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]
2011-08-07 08.07-i állapot.
    [ctt.sch, ctt_ad.sch, ctt_dp.sch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]
2011-08-09 08.09-i állapot
    [ctt.sch, ctt_ad.sch, ctt_dp.sch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]
2011-08-09 08.10. hajnali állapot
    [ctt.sch, ctt_ad.sch, ctt_dp.sch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]
2011-08-13 2011. 08. 13. de.-i állapot.
    [ctt.sch, ctt_ad.sch, ctt_dp.sch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]
2012-01-08 2012.01.08-i állapot.
    [ctt.sch, ctt_ad.sch, ctt_dp.sch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]
2012-01-08 2012.01.08. 2. feltöltés.
    [ctt.sch, ctt_ad.sch, ctt_dp.sch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]
2012-01-08 2012.01.08. 3. feltöltés.
    [ctt.sch, ctt_ad.sch, ctt_dp.sch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]
2012-01-19 2012.01.19-i feltöltés.
    [ctt_ps3.brd, ctt_ps3.sch]
2012-01-19 2012.01.19-i 3. feltöltés.
    [ctt_ps3.brd, ctt_ps3.sch]
2012-01-28 2012.01.28-i feltöltés. Új faszerkezet.
    [ctt.sch, ctt_ad.brd, ctt_ad.sch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]
2012-01-28 2012.01.28-i 2. feltöltés.
    [ctt.sch, ctt_wire.xls]
